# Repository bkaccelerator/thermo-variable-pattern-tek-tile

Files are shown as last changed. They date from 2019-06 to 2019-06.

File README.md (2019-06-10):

# Thermo-variable Pattern TEK-TILE

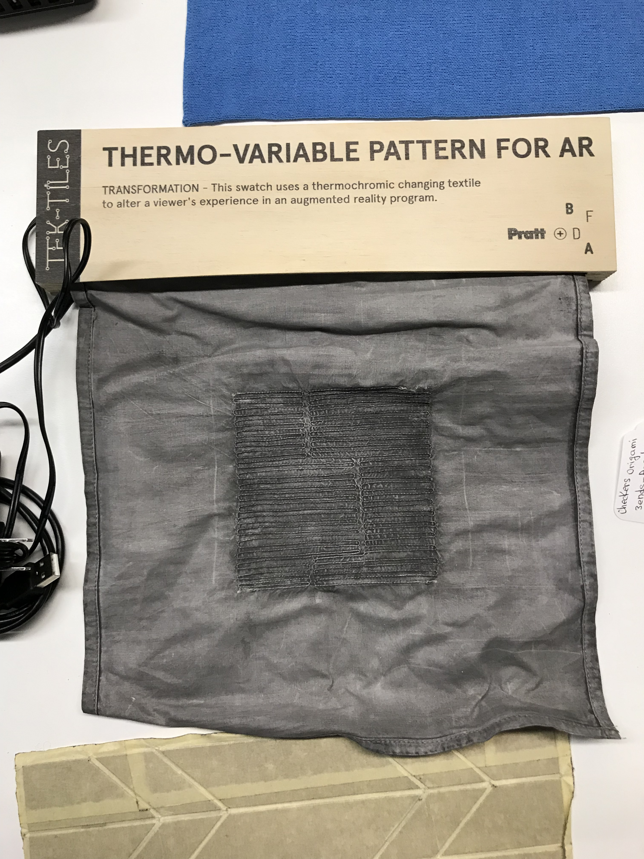
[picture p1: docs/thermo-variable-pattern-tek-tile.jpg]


A thermochromic dye makes fabric respond to heat by turning white.
Digitally-controlled heaters sewn into the material then allow the overall
pattern to be controlled by a computer.

One application is in augmented reality. The pattern can be tracked in space by
a device's camera to allow digital graphics to be overlaid. By varying the
pattern a garment can then communicate with devices using it for augmented
reality effects.

[TEK-TILES](https://bkaccelerator.com/research-all/t-lab/tek-tiles/) is a
project from the
[Brooklyn Fashion and Design Accelerator](https://bkaccelerator.com/) to develop
examples of new textile technologies.

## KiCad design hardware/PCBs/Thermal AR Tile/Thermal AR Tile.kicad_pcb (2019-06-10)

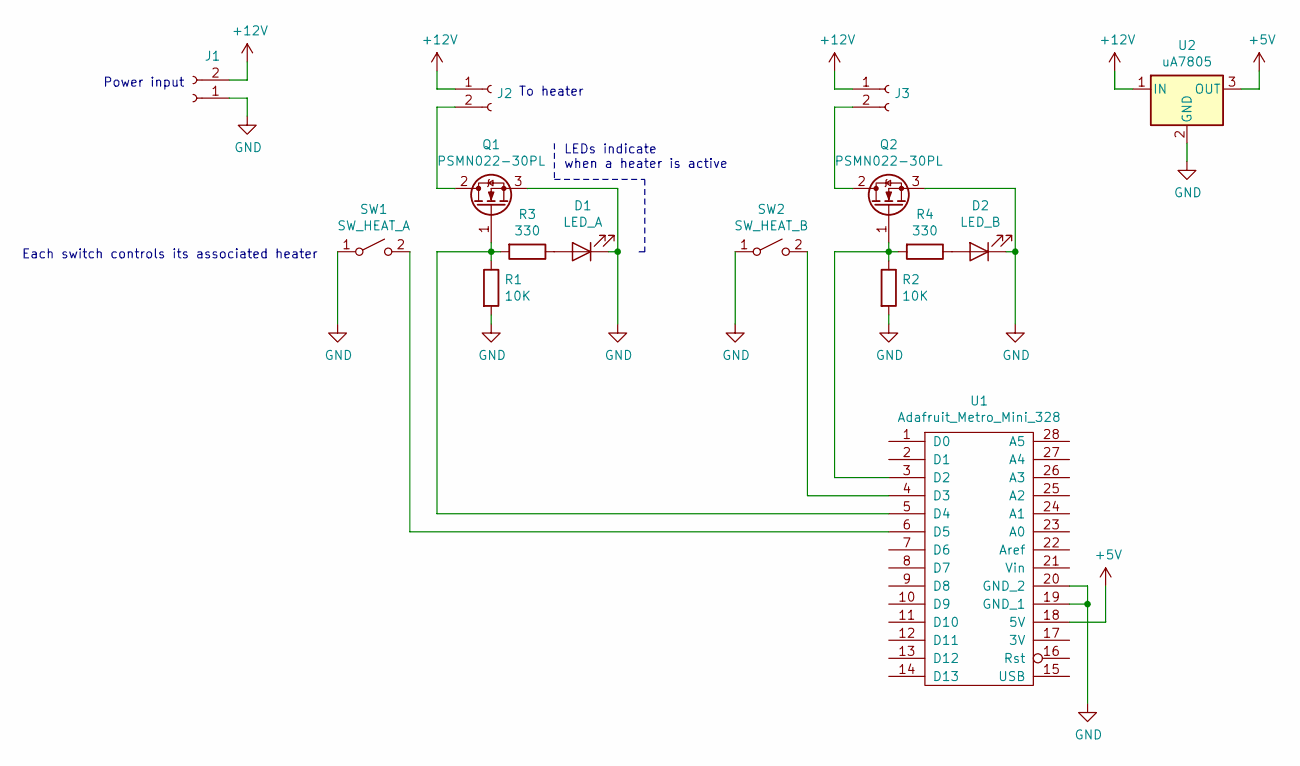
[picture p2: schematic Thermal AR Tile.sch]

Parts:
D1: LED_A; LED_D3.0mm
D2: LED_B; LED_D3.0mm
J1: Power_12V; PinHeader_1x02_P2.54mm_Vertical
J2: Heater2; PinHeader_1x02_P2.54mm_Vertical
J3: Heater1; PinHeader_1x02_P2.54mm_Vertical
Q1, Q2: PSMN022-30PL; TO-220-3_Horizontal_TabDown
R1, R2: 10K; R_Axial_DIN0207_L6.3mm_D2.5mm_P7.62mm_Horizontal
R3, R4: 330; R_Axial_DIN0207_L6.3mm_D2.5mm_P7.62mm_Horizontal
SW1: SW_HEAT_A; PinHeader_1x02_P2.54mm_Vertical
SW2: SW_HEAT_B; PinHeader_1x02_P2.54mm_Vertical
U1: Adafruit_Metro_Mini_328
U2: uA7805; TO-220-3_Horizontal_TabDown

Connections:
+5V: U1.18 (5V), U2.3 (OUT)
+12V: J1.2, J2.1, J3.1, U2.1 (IN)
GND: D1.1 (K), D2.1 (K), J1.1, Q1.3 (S), Q2.3 (S), R1.2, R2.2, SW1.1 (A), SW2.1 (A), U1.19 (GND_1), U1.20 (GND_2), U2.2 (GND)
unnamed: D1.2 (A), R3.1
unnamed: D2.2 (A), R4.1
unnamed: J2.2, Q1.2 (D)
unnamed: J3.2, Q2.2 (D)
unnamed: Q1.1 (G), R1.1, R3.2, U1.5 (D4)
unnamed: Q2.1 (G), R2.1, R4.2, U1.3 (D2)
unnamed: SW1.2 (B), U1.6 (D5)
unnamed: SW2.2 (B), U1.4 (D3)

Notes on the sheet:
Each switch controls its associated heater
LEDs indicate when a heater is active
To heater
Power input

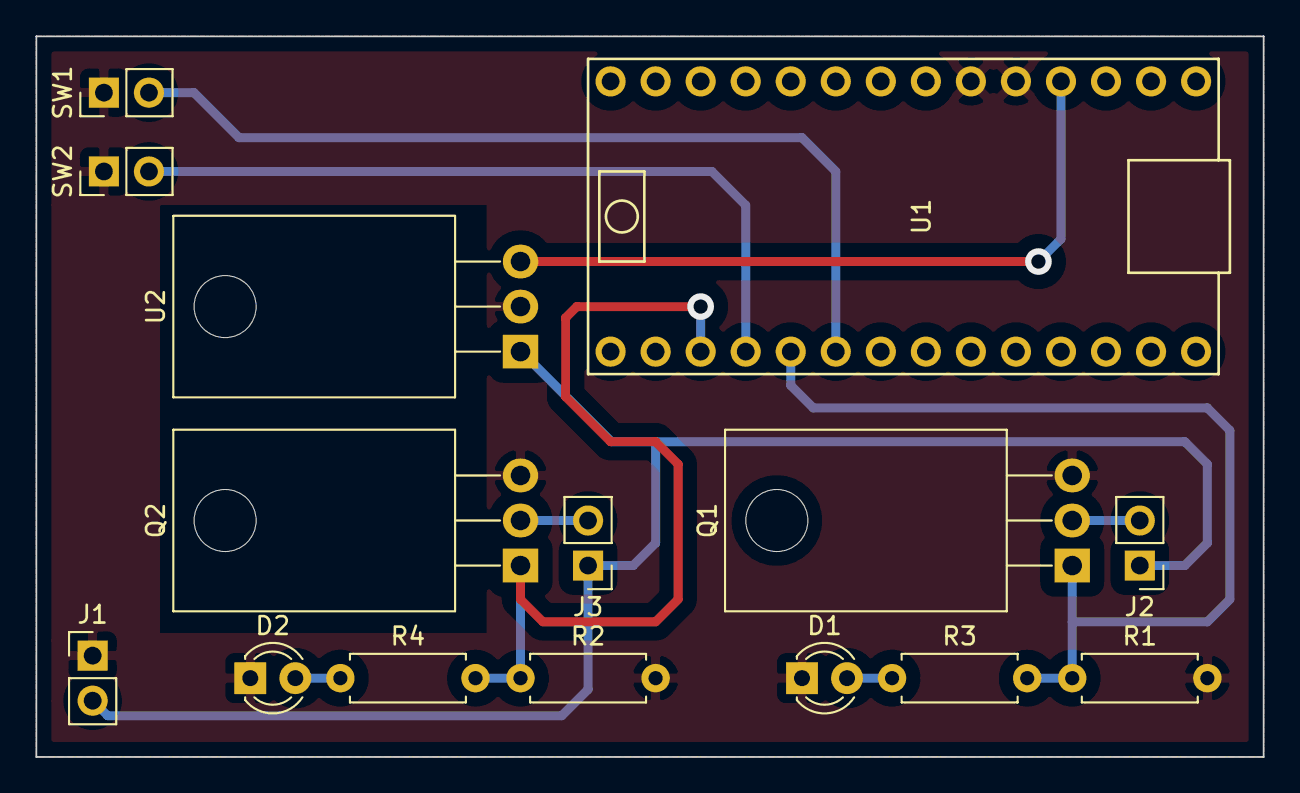
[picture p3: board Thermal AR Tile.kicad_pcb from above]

Board: 2 copper layers, 69.2 x 40.6 mm, 15 parts (0 on the bottom side), 11 nets.

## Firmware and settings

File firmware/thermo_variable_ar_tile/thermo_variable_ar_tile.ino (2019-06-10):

// Thermo-variable Pattern Tek-Tile by the Brooklyn Fashion and Design Accelerator

// This firmware implements a demo for the tile, which has two heaters and two
// buttons controlled by an Adafruit Metro Mini 328 microcontroller board.
// Once power is applied the heaters begin a heating and cooling cycle, changing
// the color of the thermochromic dye in different regions of the tile. If one
// of the buttons is pressed then the automatic control is temporarily paused
// and the buttons can be used to directly activate the heaters.

// How long to pause automatic heater control after last interaction (via buttons)
const int PAUSE_TIME = 5000;
const long ON_TIME = 20000;
const long OFF_TIME = 3 * 60000;

const int PIN_HEATER1 = 2;
const int PIN_BUTTON1 = 3;
const int PIN_HEATER2 = 4;
const int PIN_BUTTON2 = 5;

typedef enum HeatingState {
  HEATING1,
  COOLING1,
  HEATING2,
  COOLING2,
} HeatingState;

long lastEventTime = -OFF_TIME;
long pauseTime = -1;
HeatingState state = COOLING2;

void setup() {
  pinMode(PIN_HEATER1, OUTPUT);
  pinMode(PIN_HEATER2, OUTPUT);

  pinMode(PIN_BUTTON1, INPUT_PULLUP);
  pinMode(PIN_BUTTON2, INPUT_PULLUP);

  // Serial is used for debug messages
  Serial.begin(115200);
  Serial.println("Brooklyn Fashion and Design Accelerator");
  Serial.println("Thermo-Variable AR Tek-Tile");
}

bool buttonPressed(int button) {
  if (button > 1) {
    return false;
  }

  if (button == 0) {
    return !digitalRead(PIN_BUTTON1);
  } else if (button == 1) {
    return !digitalRead(PIN_BUTTON2);
  }

  return false;
}

bool isPaused() {
  if (pauseTime < 0) {
    // There have been no pauses so far
    return false;
  }

  return millis() - pauseTime < PAUSE_TIME;
}

void pause() {
  Serial.println("Paused");
  pauseTime = millis();
}

void checkButtons() {
  if (buttonPressed(0)) {
    if (!isPaused()) {
      pause();

      // Heater 2 might be on but the button not pressed
      digitalWrite(PIN_HEATER2, LOW);

      Serial.println("Button 1 pressed");
    }

    digitalWrite(PIN_HEATER1, HIGH);
  } else {
    // While paused turn the heater off if the button is not pressed
    if (isPaused()) {
      digitalWrite(PIN_HEATER1, LOW);
    }
  }

  if (buttonPressed(1)) {
    if (!isPaused()) {
      pause();

      // Heater 1 might be on but the button not pressed
      digitalWrite(PIN_HEATER1, LOW);

      Serial.println("Button 2 pressed");
    }

    digitalWrite(PIN_HEATER2, HIGH);
  } else {
    // While paused turn the heater off if the button is not pressed
    if (isPaused()) {
      digitalWrite(PIN_HEATER1, LOW);
    }
  }
}

void loop() {
  static bool wasPaused = false;
  checkButtons();

  long timeSinceLastEvent = millis() - lastEventTime;

  bool paused = isPaused();

  if (!paused && wasPaused) {
    Serial.println("Unpaused");
  }

  wasPaused = paused;

  if (!paused) {
    switch (state) {
      case HEATING1:
        digitalWrite(PIN_HEATER1, HIGH);
        
        // Transition if necessary
        if (timeSinceLastEvent > ON_TIME) {
          state = COOLING1;
          lastEventTime = millis();
          Serial.println("Cooling region 1");
        }
        break;
      case COOLING1:
        digitalWrite(PIN_HEATER1, LOW);
        
        // Transition if necessary
        if (timeSinceLastEvent > OFF_TIME) {
          state = HEATING2;
          lastEventTime = millis();
          Serial.println("Heating region 2");
        }
        break;
      case HEATING2:
        digitalWrite(PIN_HEATER2, HIGH);
        
        // Transition if necessary
        if (timeSinceLastEvent > ON_TIME) {
          state = COOLING2;
          lastEventTime = millis();
          Serial.println("Cooling region 2");
        }
        break;
      case COOLING2:
        digitalWrite(PIN_HEATER2, LOW);
        
        // Transition if necessary
        if (timeSinceLastEvent > OFF_TIME) {
          state = HEATING1;
          lastEventTime = millis();
          Serial.println("Heating region 1");
        }
        break;
    }
  }
}
